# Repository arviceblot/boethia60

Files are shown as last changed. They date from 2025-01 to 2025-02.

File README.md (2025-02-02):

# boethia60

A low profile, hotswap keyboard inspired by the HHBK layout, powered by [rmk](https://github.com/haobogu/rmk) with the rp2040 MCU.

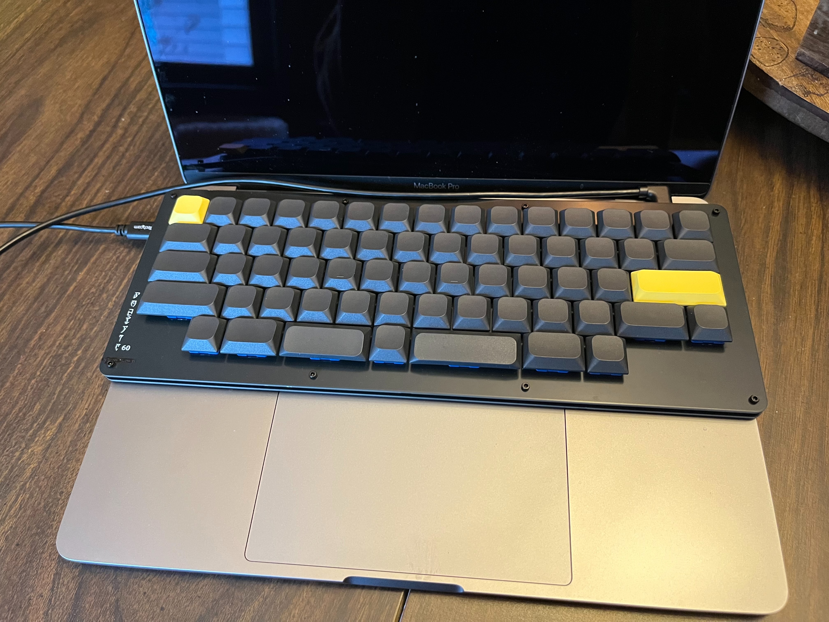
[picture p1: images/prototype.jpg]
assembled prototype


## Features

- Low profile, with compatility for Choc V1 and V2 switches
- Vial support for realtime keymap changes
- HHKB style layout with split spacebars
- ESD protection because winters here are dry AF

## Layout

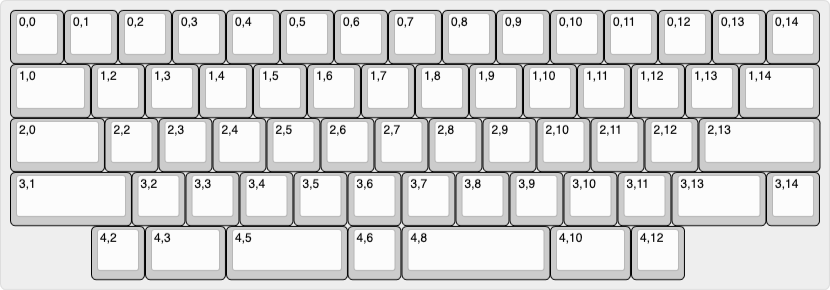
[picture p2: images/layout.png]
keyboard layout


## Possible Improvements

- [ ] Relocate the USB connector to the left side.
- [ ] Change the USB connector to a mid-mount version. Right now, the bottom plate needs a cutout to fit the connector.

## Notes

This keyboard was mainly created as a learning experience. Most likely improvements could be made to the trace routing and other aspects.

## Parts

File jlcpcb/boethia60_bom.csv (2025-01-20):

Reference | Value | Datasheet | Footprint | Qty | JLCPCB Part
C1,C4 | 22p | ~ | Capacitor_SMD:C_0402_1005Metric | 2 | C1555
C2,C3,C5,C13 | 1u | ~ | Capacitor_SMD:C_0402_1005Metric | 4 | C52923
C6,C7,C8,C9,C10,C11,C12,C14,C15,C16 | 100n | ~ | Capacitor_SMD:C_0402_1005Metric | 10 | C1525
D_1,D_2,D_3,D_4,D_5,D_6,D_7,D_8,D_9,D_10,D_11,D_12,D_13,D_14,D_15,D_16,D_17,D_18,D_19,D_20,D_21,D_22,D_23,D_24,D_25,D_26,D_27,D_28,D_29,D_30,D_31,D_32,D_33,D_34,D_35,D_36,D_37,D_38,D_39,D_40,D_41,D_42,D_43,D_44,D_45,D_46,D_47,D_48,D_49,D_50,D_51,D_52,D_53,D_54,D_55,D_56,D_57,D_58,D_59,D_60,D_61,D_62 | D | ~ | Diode_SMD:D_SOD-323 | 62 | C2128
F1 | 500m | ~ | Fuse:Fuse_0805_2012Metric | 1 | C1015
FB1 | 60@100MHz | ~ | Inductor_SMD:L_0603_1608Metric | 1 | C14709
R1,R2,R7 | 1k | ~ | Resistor_SMD:R_0402_1005Metric | 3 | C11702
R3,R4 | 27.4 | ~ | Resistor_SMD:R_0402_1005Metric | 2 | C274349
R5,R6 | 5.1k | ~ | Resistor_SMD:R_0402_1005Metric | 2 | C25905
SW1 | SW_Push | ~ | Button_Switch_SMD:SW_SPST_SKQG_WithStem | 1 | C318884
U1 | NCP1117-3.3_SOT223 | http://www.onsemi.com/pub_link/Collateral/NCP1117-D.PDF | Package_TO_SOT_SMD:SOT-23-3 | 1 | C5446
U2 | PRTR5V0U2X |  | Package_TO_SOT_SMD:SOT-143 | 1 | C2827688
U3 | RP2040 | https://datasheets.raspberrypi.com/rp2040/rp2040-datasheet.pdf | Package_DFN_QFN:QFN-56-1EP_7x7mm_P0.4mm_EP3.2x3.2mm | 1 | C2040
U4 | W25Q128JVS | https://www.winbond.com/resource-files/w25q128jv_dtr%20revc%2003272018%20plus.pdf | Package_SO:SOIC-8_5.23x5.23mm_P1.27mm | 1 | C82317
USB1 | HRO-TYPE-C-31-M-12 |  | Type-C:HRO-TYPE-C-31-M-12-HandSoldering | 1 | C165948
Y1 | Crystal_GND24_Small | ~ | Crystal:Crystal_SMD_3225-4Pin_3.2x2.5mm | 1 | C9002

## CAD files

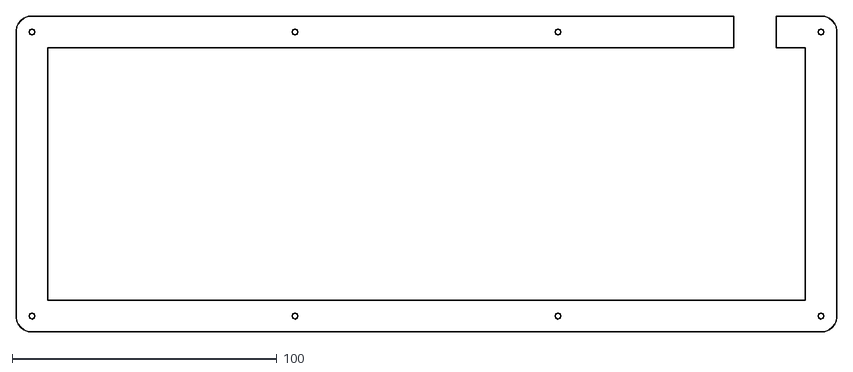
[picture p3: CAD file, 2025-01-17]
case/0cebd8e7179c38d7ca830ee3c2892adf3e2daf86_open.dxf
309.8 x 119.2

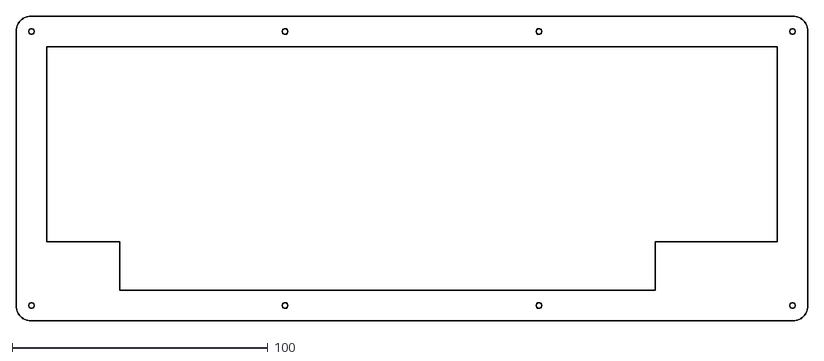
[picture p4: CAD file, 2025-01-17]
case/0cebd8e7179c38d7ca830ee3c2892adf3e2daf86_top.dxf
309.8 x 119.2

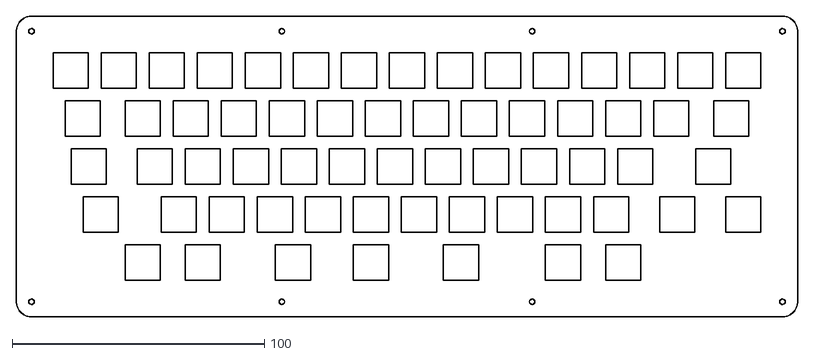
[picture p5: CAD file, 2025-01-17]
case/0cebd8e7179c38d7ca830ee3c2892adf3e2daf86_switch.dxf
309.8 x 119.2

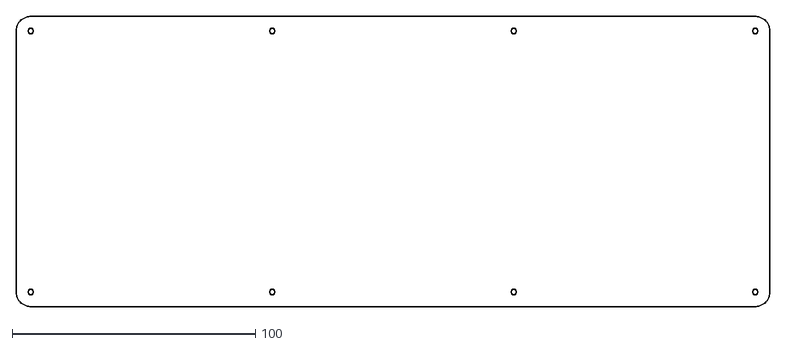
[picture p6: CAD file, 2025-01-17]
case/0cebd8e7179c38d7ca830ee3c2892adf3e2daf86_bottom.dxf
309.8 x 119.2

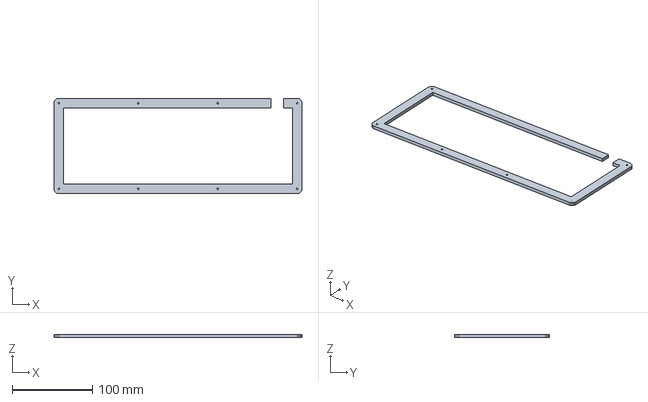
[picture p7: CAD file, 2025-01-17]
case/Middle.FCStd
309.8 x 119.2 x 4.00 mm

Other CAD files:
case/boethia60 case.stl

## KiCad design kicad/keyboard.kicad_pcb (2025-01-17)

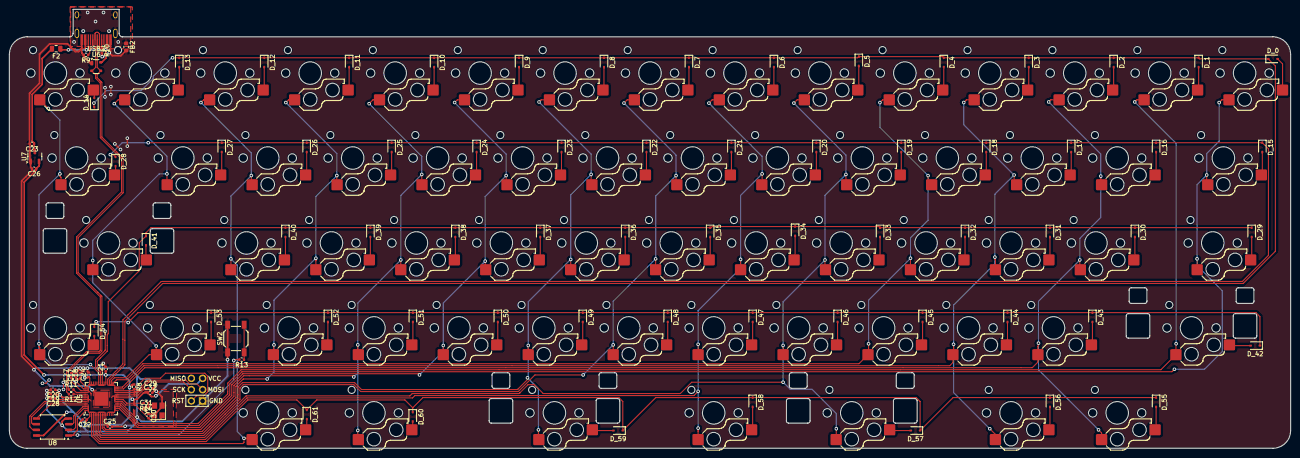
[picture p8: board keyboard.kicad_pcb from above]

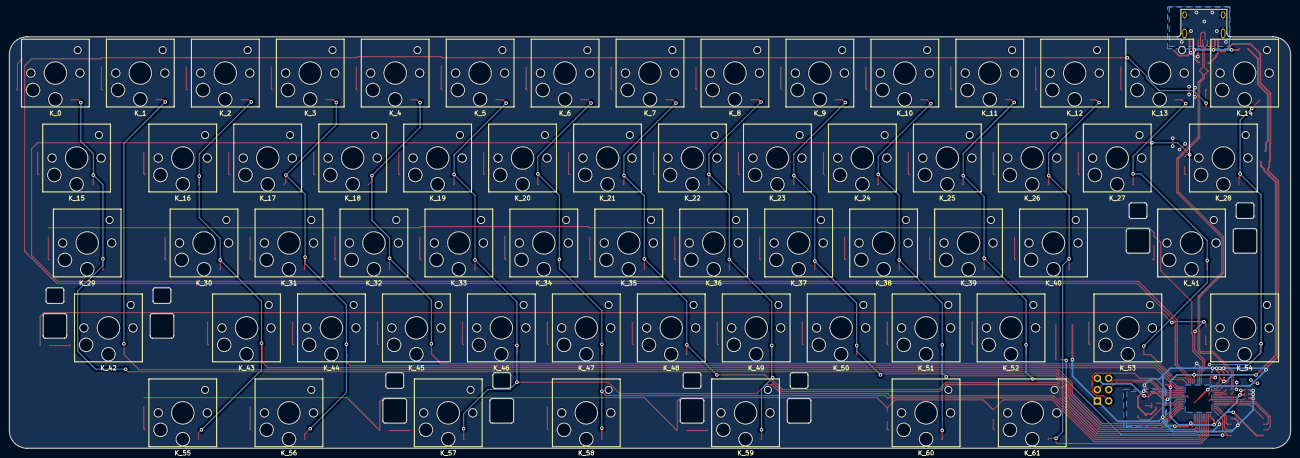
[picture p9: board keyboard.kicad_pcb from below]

Board: 2 copper layers, 287.3 x 98.4 mm, 157 parts (62 on the bottom side), 107 nets.

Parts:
C17, C23, C26, C27: 1u; C_0402_1005Metric
C18, C19, C20, C21, C22, C24, C25, C28, C29, C32: 100n; C_0402_1005Metric
C30, C31: 22p; C_0402_1005Metric
D_0, D_1, D_2, D_3, D_4, D_5, D_6, D_7, D_8, D_9, D_10, D_11, D_12, D_13, D_14, D_15, D_16, D_17, D_18, D_19, D_20, D_21, D_22, D_23, D_24, D_25, D_26, D_27, D_28, D_29, D_30, D_31, D_32, D_33, D_34, D_35, D_36, D_37, D_38, D_39, D_40, D_41, D_42, D_43, D_44, D_45, D_46, D_47, D_48, D_49, D_50, D_51, D_52, D_53, D_54, D_55, D_56, D_57, D_58, D_59, D_60, D_61: D; D_SOD-323
F2: 500m; Fuse_0805_2012Metric
FB2: 60@100MHz; L_0603_1608Metric
J2: Conn_01x06; Reset_Pretty-Mask
K_0, K_1, K_2, K_3, K_4, K_5, K_6, K_7, K_8, K_9, K_10, K_11, K_12, K_13, K_14, K_15, K_16, K_17, K_18, K_19, K_20, K_21, K_22, K_23, K_24, K_25, K_26, K_27, K_28, K_29, K_30, K_31, K_32, K_33, K_34, K_35, K_36, K_37, K_38, K_39, K_40, K_41, K_42, K_43, K_44, K_45, K_46, K_47, K_48, K_49, K_50, K_51, K_52, K_53, K_54, K_55, K_56, K_57, K_58, K_59, K_60, K_61: KEYSW; SW_Hotswap_Kailh_Choc_V1V2
R8, R13, R14: 1k; R_0402_1005Metric
R9, R10: 5.1k; R_0402_1005Metric
R11, R12: 27.4; R_0402_1005Metric
SW2: SW_Push; SW_SPST_SKQG_WithStem
U5: RP2040; QFN-56-1EP_7x7mm_P0.4mm_EP3.2x3.2mm
U6: PRTR5V0U2X; SOT-143
U7: NCP1117-3.3_SOT223; SOT-23-3
U8: W25Q128JVS; SOIC-8_5.23x5.23mm_P1.27mm
USB2: HRO-TYPE-C-31-M-12; HRO-TYPE-C-31-M-12-HandSoldering
Y2: Crystal_GND24_Small; Crystal_SMD_3225-4Pin_3.2x2.5mm

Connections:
+1V1: C27.1, C28.1, C29.1, U5.23 (DVDD), U5.45 (VREG_VOUT), U5.50 (DVDD)
+3V3: C17.1, C18.1, C19.1, C20.1, C21.1, C22.1, C24.1, C25.1, C26.1, C32.1, J2.2, R8.1, U5.1 (IOVDD), U5.10 (IOVDD), U5.22 (IOVDD), U5.33 (IOVDD), U5.42 (IOVDD), U5.43 (ADC_AVDD), U5.44 (VREG_IN), U5.48 (USB_VDD), U5.49 (IOVDD), U7.2 (VO), U8.8 (VCC)
+5V: C23.1, F2.2, U7.3 (VI)
/CS: R13.2, U5.56 (QSPI_SS), U8.1 (~CS)
/D+: R12.1, U5.47 (USB_DP)
/D-: R11.2, U5.46 (USB_DM)
/RUN: J2.5, R8.2, U5.26 (RUN)
/SCLK: U5.52 (QSPI_SCLK), U8.6 (CLK)
/SD0: U5.53 (QSPI_SD0), U8.5 (DI(IO0))
/SD1: U5.55 (QSPI_SD1), U8.2 (DO(IO1))
/SD2: U5.54 (QSPI_SD2), U8.3 (IO2)
/SD3: U5.51 (QSPI_SD3), U8.7 (IO3)
/SWCLK: J2.3, U5.24 (SWCLK)
/SWD: J2.4, U5.25 (SWD)
/XIN: C30.2, U5.20 (XIN), Y2.1
/XOUT: R14.2, U5.21 (XOUT)
DN: R11.1, U6.3 (IO2), USB2.5 (DN2), USB2.7 (DN1)
DP: R12.2, U6.2 (IO1), USB2.6 (DP1), USB2.8 (DP2)
Earth: FB2.1, USB2.13 (SHIELD)
GND: C17.2, C18.2, C19.2, C20.2, C21.2, C22.2, C23.2, C24.2, C25.2, C26.2, C27.2, C28.2, C29.2, C30.1, C31.1, C32.2, FB2.2, J2.6, R9.2, R10.2, SW2.1, U5.19 (TESTEN), U5.57 (GND), U6.1 (GND), U7.1 (GND), U8.4 (GND), USB2.1 (GND), USB2.12 (GND), Y2.2, Y2.4
unnamed: C31.2, R14.1, Y2.3
unnamed: D_0.2 (A), K_0.2 (ROW)
unnamed: D_1.2 (A), K_1.2 (ROW)
unnamed: D_2.2 (A), K_2.2 (ROW)
unnamed: D_3.2 (A), K_3.2 (ROW)
unnamed: D_4.2 (A), K_4.2 (ROW)
unnamed: D_5.2 (A), K_5.2 (ROW)
unnamed: D_6.2 (A), K_6.2 (ROW)
unnamed: D_7.2 (A), K_7.2 (ROW)
unnamed: D_8.2 (A), K_8.2 (ROW)
unnamed: D_9.2 (A), K_9.2 (ROW)
unnamed: D_10.2 (A), K_10.2 (ROW)
unnamed: D_11.2 (A), K_11.2 (ROW)
unnamed: D_12.2 (A), K_12.2 (ROW)
unnamed: D_13.2 (A), K_13.2 (ROW)
unnamed: D_14.2 (A), K_14.2 (ROW)
unnamed: D_15.2 (A), K_15.2 (ROW)
unnamed: D_16.2 (A), K_16.2 (ROW)
unnamed: D_17.2 (A), K_17.2 (ROW)
unnamed: D_18.2 (A), K_18.2 (ROW)
unnamed: D_19.2 (A), K_19.2 (ROW)
unnamed: D_20.2 (A), K_20.2 (ROW)
unnamed: D_21.2 (A), K_21.2 (ROW)
unnamed: D_22.2 (A), K_22.2 (ROW)
unnamed: D_23.2 (A), K_23.2 (ROW)
unnamed: D_24.2 (A), K_24.2 (ROW)
unnamed: D_25.2 (A), K_25.2 (ROW)
unnamed: D_26.2 (A), K_26.2 (ROW)
unnamed: D_27.2 (A), K_27.2 (ROW)
unnamed: D_28.2 (A), K_28.2 (ROW)
unnamed: D_29.2 (A), K_29.2 (ROW)
unnamed: D_30.2 (A), K_30.2 (ROW)
unnamed: D_31.2 (A), K_31.2 (ROW)
unnamed: D_32.2 (A), K_32.2 (ROW)
unnamed: D_33.2 (A), K_33.2 (ROW)
unnamed: D_34.2 (A), K_34.2 (ROW)
unnamed: D_35.2 (A), K_35.2 (ROW)
unnamed: D_36.2 (A), K_36.2 (ROW)
unnamed: D_37.2 (A), K_37.2 (ROW)
unnamed: D_38.2 (A), K_38.2 (ROW)
unnamed: D_39.2 (A), K_39.2 (ROW)
unnamed: D_40.2 (A), K_40.2 (ROW)
unnamed: D_41.2 (A), K_41.2 (ROW)
unnamed: D_42.2 (A), K_42.2 (ROW)
unnamed: D_43.2 (A), K_43.2 (ROW)
unnamed: D_44.2 (A), K_44.2 (ROW)
unnamed: D_45.2 (A), K_45.2 (ROW)
unnamed: D_46.2 (A), K_46.2 (ROW)
unnamed: D_47.2 (A), K_47.2 (ROW)
unnamed: D_48.2 (A), K_48.2 (ROW)
unnamed: D_49.2 (A), K_49.2 (ROW)
unnamed: D_50.2 (A), K_50.2 (ROW)
unnamed: D_51.2 (A), K_51.2 (ROW)
unnamed: D_52.2 (A), K_52.2 (ROW)
unnamed: D_53.2 (A), K_53.2 (ROW)
unnamed: D_54.2 (A), K_54.2 (ROW)
unnamed: D_55.2 (A), K_55.2 (ROW)
unnamed: D_56.2 (A), K_56.2 (ROW)
unnamed: D_57.2 (A), K_57.2 (ROW)
unnamed: D_58.2 (A), K_58.2 (ROW)
unnamed: D_59.2 (A), K_59.2 (ROW)
unnamed: D_60.2 (A), K_60.2 (ROW)
unnamed: D_61.2 (A), K_61.2 (ROW)
unnamed: R13.1, SW2.2
unnamed: R10.1, USB2.4 (CC1)
unnamed: R9.1, USB2.10 (CC2)
VBUS: F2.1, U6.4 (VCC), USB2.2 (VBUS), USB2.11 (VBUS)
col0: K_0.1 (COL), K_15.1 (COL), K_29.1 (COL), U5.17 (GPIO14)
col1: K_1.1 (COL), K_42.1 (COL), U5.18 (GPIO15)
col2: K_2.1 (COL), K_16.1 (COL), K_30.1 (COL), K_43.1 (COL), K_55.1 (COL), U5.27 (GPIO16)
col3: K_3.1 (COL), K_17.1 (COL), K_31.1 (COL), K_44.1 (COL), K_56.1 (COL), U5.28 (GPIO17)
col4: K_4.1 (COL), K_18.1 (COL), K_32.1 (COL), K_45.1 (COL), U5.29 (GPIO18)
col5: K_5.1 (COL), K_19.1 (COL), K_33.1 (COL), K_46.1 (COL), K_57.1 (COL), U5.5 (GPIO3)
col6: K_6.1 (COL), K_20.1 (COL), K_34.1 (COL), K_47.1 (COL), K_58.1 (COL), U5.4 (GPIO2)
col7: K_7.1 (COL), K_21.1 (COL), K_35.1 (COL), K_48.1 (COL), U5.6 (GPIO4)
col8: K_8.1 (COL), K_22.1 (COL), K_36.1 (COL), K_49.1 (COL), K_59.1 (COL), U5.7 (GPIO5)
col9: K_9.1 (COL), K_23.1 (COL), K_37.1 (COL), K_50.1 (COL), U5.16 (GPIO13)
col10: K_10.1 (COL), K_24.1 (COL), K_38.1 (COL), K_51.1 (COL), K_60.1 (COL), U5.9 (GPIO7)
col11: K_11.1 (COL), K_25.1 (COL), K_39.1 (COL), K_52.1 (COL), U5.8 (GPIO6)
col12: K_12.1 (COL), K_26.1 (COL), K_40.1 (COL), K_61.1 (COL), U5.2 (GPIO0)
col13: K_13.1 (COL), K_27.1 (COL), K_41.1 (COL), K_53.1 (COL), U5.30 (GPIO19)
col14: K_14.1 (COL), K_28.1 (COL), K_54.1 (COL), U5.37 (GPIO25)
row0: D_0.1 (K), D_1.1 (K), D_2.1 (K), D_3.1 (K), D_4.1 (K), D_5.1 (K), D_6.1 (K), D_7.1 (K), D_8.1 (K), D_9.1 (K), D_10.1 (K), D_11.1 (K), D_12.1 (K), D_13.1 (K), D_14.1 (K), U5.31 (GPIO20)
row1: D_15.1 (K), D_16.1 (K), D_17.1 (K), D_18.1 (K), D_19.1 (K), D_20.1 (K), D_21.1 (K), D_22.1 (K), D_23.1 (K), D_24.1 (K), D_25.1 (K), D_26.1 (K), D_27.1 (K), D_28.1 (K), U5.32 (GPIO21)
row2: D_29.1 (K), D_30.1 (K), D_31.1 (K), D_32.1 (K), D_33.1 (K), D_34.1 (K), D_35.1 (K), D_36.1 (K), D_37.1 (K), D_38.1 (K), D_39.1 (K), D_40.1 (K), D_41.1 (K), U5.35 (GPIO23)
row3: D_42.1 (K), D_43.1 (K), D_44.1 (K), D_45.1 (K), D_46.1 (K), D_47.1 (K), D_48.1 (K), D_49.1 (K), D_50.1 (K), D_51.1 (K), D_52.1 (K), D_53.1 (K), D_54.1 (K), U5.36 (GPIO24)
row4: D_55.1 (K), D_56.1 (K), D_57.1 (K), D_58.1 (K), D_59.1 (K), D_60.1 (K), D_61.1 (K), U5.3 (GPIO1)

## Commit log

2025-01-11 Initial import
    [boethia60.kicad_pcb, boethia60.kicad_sch]
2025-01-14 Everything is coming together.
    [boethia60.kicad_pcb, boethia60.kicad_sch, matrix.kicad_sch]
2025-01-14 Fixed lonely column.
    [boethia60.kicad_pcb, matrix.kicad_sch]
2025-01-14 Change footprints, fix errors, WIP BOM.
    [boethia60-B_Cu.gbr, boethia60-B_Mask.gbr, boethia60-B_Paste.gbr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]
2025-01-15 Fix firmware pins.
    [boethia60-B_Cu.gbr, boethia60-B_Mask.gbr, boethia60-B_Paste.gbr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]
2025-01-16 Add another kicad project version.
    [boethia60.kicad_sch, keyboard.kicad_pcb, keyboard.kicad_sch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]
2025-01-17 Complete routing and fill zones.
    [keyboard.kicad_pcb, keyboard.kicad_sch]
2025-01-17 Add preview plate and case files.
    [0cebd8e7179c38d7ca830ee3c2892adf3e2daf86_bottom.dxf, 0cebd8e7179c38d7ca830ee3c2892adf3e2daf86_open.dxf, 0cebd8e7179c38d7ca830ee3c2892adf3e2daf86_switch.dxf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]
2025-01-18 Update annotations.
    [boethia60_bom.csv, keyboard.kicad_sch]
2025-01-18 Update firmware for new schematic.
2025-01-18 Add top and bottom plates.
    [boethia60-B_Cu.gbr, boethia60-B_Mask.gbr, boethia60-B_Paste.gbr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]
2025-01-20 Fix incorrect package BOM item.
    [boethia60.kicad_sch, boethia60_bom.csv]
2025-02-01 Add prototype image
